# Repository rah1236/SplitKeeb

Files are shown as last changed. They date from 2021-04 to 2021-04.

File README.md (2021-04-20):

# SplitKeeb

### SplitKeeb is my custom designed split keyboard based on the QMK Firmware and 2 Arduino Pro Micros.

Split Keyboard
(No keycaps because I can't afford them at the moment :])

KiCad view

Real Life PCB

This is a *split* keyboard design, and uses I2C to communicate over a TRRS audio cable (4 poles). 

The parts list is as follows:
* 62 of any Cherry MX style key Switch
* 62 1N4148 Zener Diodes
* 2 identical Resistors from a range of 2.2k Ohms to 10k Ohms (4.7k recommended) 
* 2 Arduino Pro Micros
* 2 PJ-320A TRRS Female Jacks
* 1 TRRS Male to Male wire
* 10 M3 x 8mm Bolts
* 10 M3 nuts

The 2 resistors are for the I2C line, make sure to solder them to whichever board you want to use as the 'main' side.

Make sure to plug in the TRRS cable **BEFORE** you plug in the USB cable, otherwise you risk shorts as the TRRS cable supplies power to the other board.

To program the keyboard, the eaisest method is to use the [QMK Toolbox](https://github.com/qmk/qmk_toolbox), and flash both Pro Micros with the same 'SplitKeeb.hex' file. After both boards have been flashed, plug in the TRRS cable, and then plug in USB, and the keyboard should work as normal. 

Thanks to Rayyan and David for helping me figure out the firmware :)

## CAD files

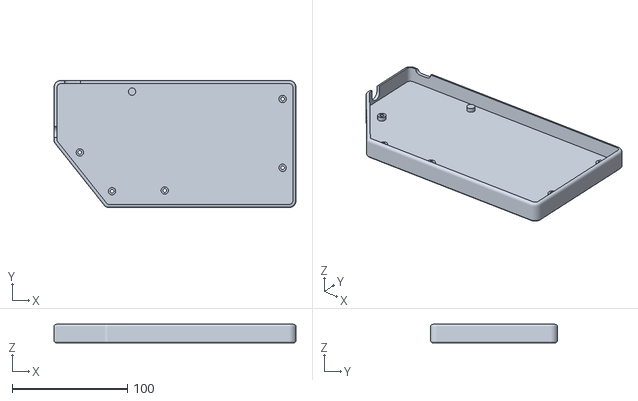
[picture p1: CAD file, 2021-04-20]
CaseFiles/RightSide.stl
209.9 x 110.2 x 16.1

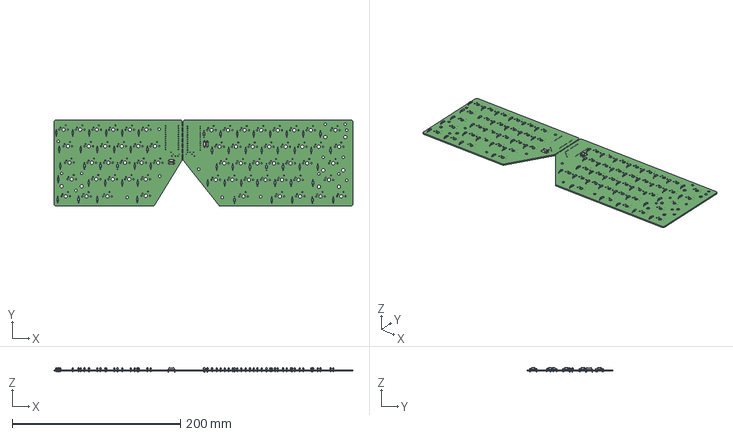
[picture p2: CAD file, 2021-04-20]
SplitKeebKiCad/kb.step
355.6 x 102.2 x 5.51 mm

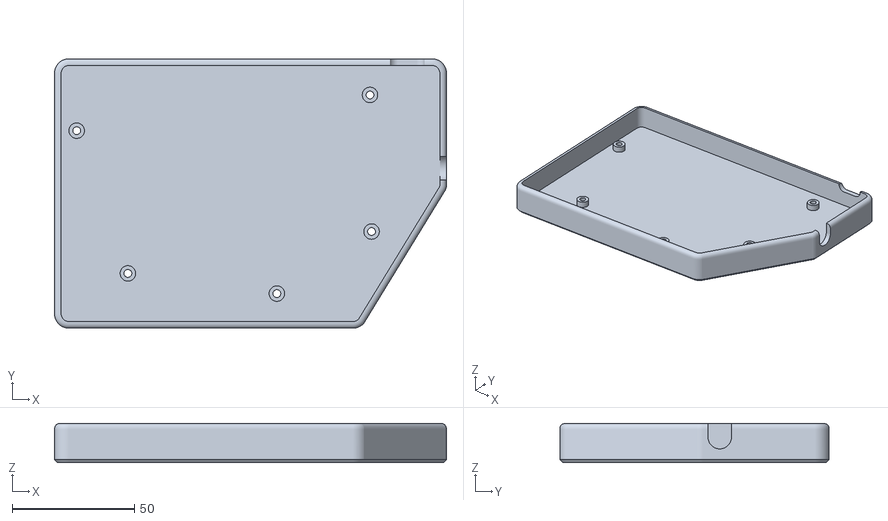
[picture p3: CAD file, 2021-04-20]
CaseFiles/LeftSide.stl
160.4 x 110.2 x 16.1

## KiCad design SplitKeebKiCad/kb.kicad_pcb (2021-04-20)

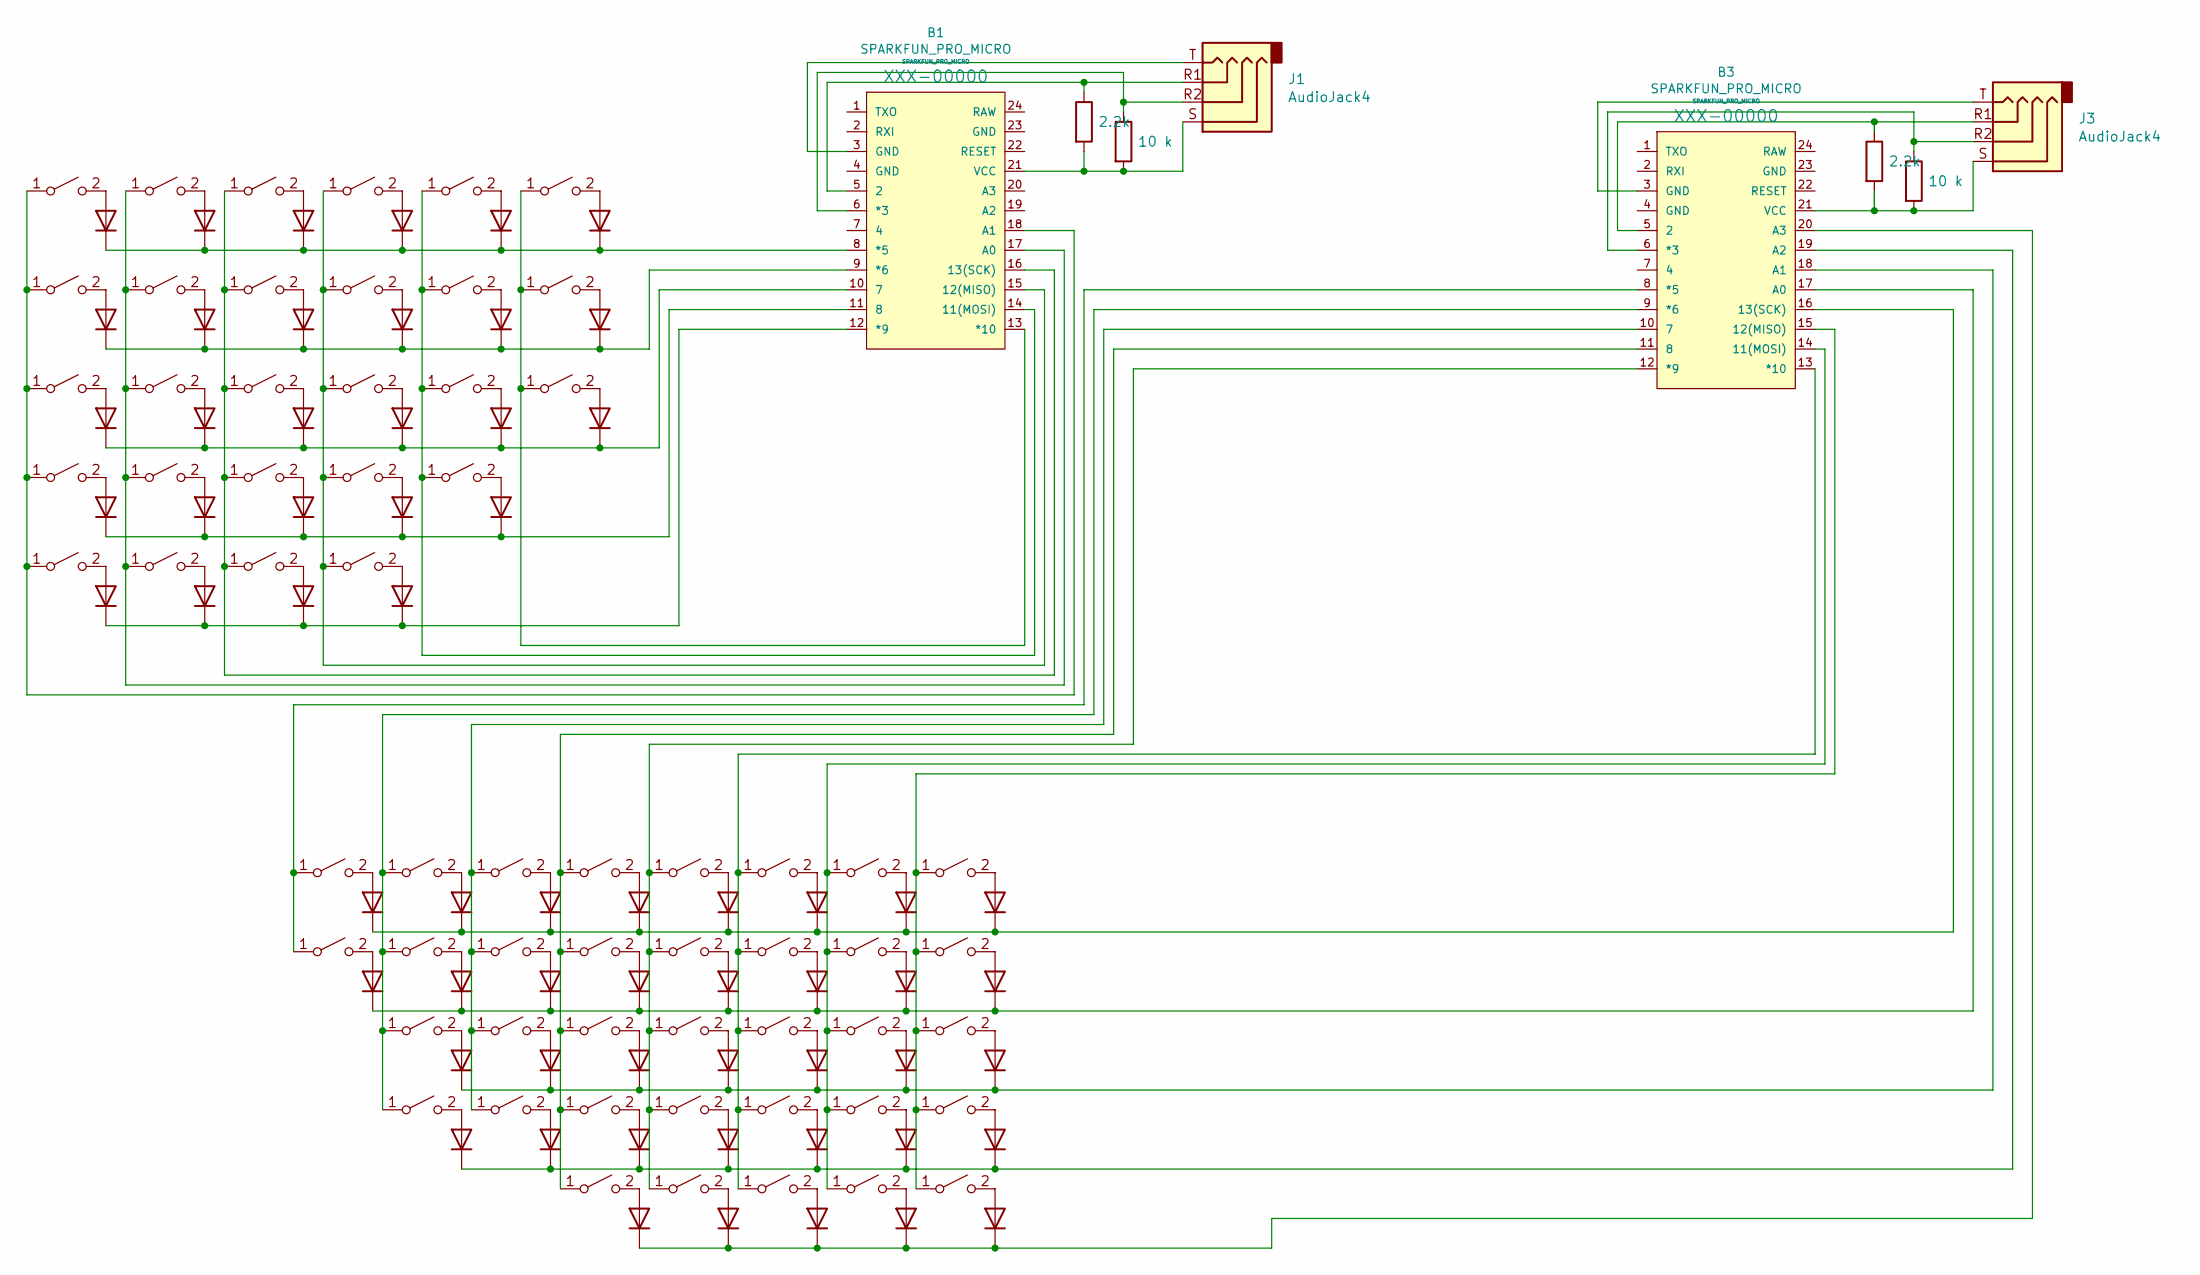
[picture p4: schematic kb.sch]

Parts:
A1: Q; SW_Cherry_MX_1.00u_PCB
Alt1: Q; SW_Cherry_MX_1.25u_PCB
B1, B3: SPARKFUN_PRO_MICRO
B2: b; SW_Cherry_MX_1.00u_PCB
Bar1: |; SW_Cherry_MX_1.50u_PCB
Bckspce1: Back; SW_Cherry_MX_2.00u_PCB
C1: Q; SW_Cherry_MX_1.00u_PCB
Caps1: Q; SW_Cherry_MX_1.75u_PCB
Colon1: ;; SW_Cherry_MX_1.00u_PCB
Ctrl1: Q; SW_Cherry_MX_1.25u_PCB
D1, D2, D3, D4, D5, D6, D7, D8, D9, D10, D11, D12, D13, D14, D15, D16, D17, D18, D19, D20, D21, D22, D23, D24, D25, D26, D27, D29, D30, D31, D32, D33, D34, D35, D36, D37, D38, D39, D40, D41, D42, D43, D44, D45, D46, D47, D48, D49, D50, D51, D52, D53, D54, D55, D56, D57, D58, D59, D60, D61, D62, D63: 1N4148; D_DO-35_SOD27_P7.62mm_Horizontal
D28: Q; SW_Cherry_MX_1.00u_PCB
E1: Q; SW_Cherry_MX_1.00u_PCB
Eight1: 8; SW_Cherry_MX_1.00u_PCB
Enter1: enter; SW_Cherry_MX_2.25u_PCB
EqualsSign1: =+; SW_Cherry_MX_1.00u_PCB
F1: Q; SW_Cherry_MX_1.00u_PCB
Five1: Q; SW_Cherry_MX_1.00u_PCB
Four1: Q; SW_Cherry_MX_1.00u_PCB
G1: Q; SW_Cherry_MX_1.00u_PCB
H1: h; SW_Cherry_MX_1.00u_PCB
I1: i; SW_Cherry_MX_1.00u_PCB
J1, J3: AudioJack4; TRRS-PJ-320A
J2: j; SW_Cherry_MX_1.00u_PCB
K1: k; SW_Cherry_MX_1.00u_PCB
L1: l; SW_Cherry_MX_1.00u_PCB
LeftAligator1: <; SW_Cherry_MX_1.00u_PCB
LeftBracket1: [; SW_Cherry_MX_1.00u_PCB
M1: m; SW_Cherry_MX_1.00u_PCB
MenuButton1: Menu; SW_Cherry_MX_1.25u_PCB
N1: n; SW_Cherry_MX_1.00u_PCB
Nine1: 9; SW_Cherry_MX_1.00u_PCB
O1: o; SW_Cherry_MX_1.00u_PCB
One1: 1; SW_Cherry_MX_1.00u_PCB
P1: p; SW_Cherry_MX_1.00u_PCB
Q1: Q; SW_Cherry_MX_1.00u_PCB
QuestionMark1: ?; SW_Cherry_MX_1.00u_PCB
QuoteSign1: \"; SW_Cherry_MX_1.00u_PCB
R1, R4: 2.2k; R_Axial_DIN0207_L6.3mm_D2.5mm_P7.62mm_Horizontal
R2, R5: 10 k; R_Axial_DIN0207_L6.3mm_D2.5mm_P7.62mm_Horizontal
R3: Q; SW_Cherry_MX_1.00u_PCB
RightAlligaotr1: >; SW_Cherry_MX_1.00u_PCB
RightAlt1: RAlt; SW_Cherry_MX_1.25u_PCB
RightBracket1: ]; SW_Cherry_MX_1.00u_PCB
RightCtrl1: RCTRL; SW_Cherry_MX_1.25u_PCB
RightShift1: RShift; SW_Cherry_MX_2.75u_PCB
RightSpace1: RSpace; SW_Cherry_MX_1.00u_PCB
RightWindows1: RWindows; SW_Cherry_MX_1.25u_PCB
S1: Q; SW_Cherry_MX_1.00u_PCB
Seven1: 7; SW_Cherry_MX_1.00u_PCB
Shift1: Q; SW_Cherry_MX_2.25u_PCB
Six1: 6; SW_Cherry_MX_1.00u_PCB
Space1: Q; SW_Cherry_MX_1.00u_PCB
T1: Q; SW_Cherry_MX_1.00u_PCB
Tab1: esc; SW_Cherry_MX_1.50u_PCB
Two1: Q; SW_Cherry_MX_1.00u_PCB
U1: u; SW_Cherry_MX_1.00u_PCB
UnderScore1: _; SW_Cherry_MX_1.00u_PCB
V1: Q; SW_Cherry_MX_1.00u_PCB
W1: Q; SW_Cherry_MX_1.00u_PCB
Windows1: Q; SW_Cherry_MX_1.25u_PCB
X1: Q; SW_Cherry_MX_1.00u_PCB
Y1: y; SW_Cherry_MX_1.00u_PCB
Z1: Q; SW_Cherry_MX_1.00u_PCB
Zero1: 0; SW_Cherry_MX_1.00u_PCB
esc1: esc; SW_Cherry_MX_1.00u_PCB
three1: Q; SW_Cherry_MX_1.00u_PCB

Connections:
unnamed: A1.1 (A), B1.17 (A0), One1.1 (A), Q1.1 (A), Windows1.1 (A), Z1.1 (A)
unnamed: A1.2 (B), D8.2 (A)
unnamed: Alt1.1 (A), B1.16 (13(SCK)), S1.1 (A), Two1.1 (A), W1.1 (A), X1.1 (A)
unnamed: Alt1.2 (B), D15.2 (A)
unnamed: B1.5 (2), J1.R1, R1.1
unnamed: B1.6 (*3), J1.R2, R2.1
unnamed: B1.8 (*5), D1.1 (K), D6.1 (K), D11.1 (K), D16.1 (K), D21.1 (K), D25.1 (K)
unnamed: B1.9 (*6), D2.1 (K), D7.1 (K), D12.1 (K), D17.1 (K), D22.1 (K), D26.1 (K)
unnamed: B1.10 (7), D3.1 (K), D8.1 (K), D13.1 (K), D18.1 (K), D23.1 (K), D27.1 (K)
unnamed: B1.11 (8), D4.1 (K), D9.1 (K), D14.1 (K), D19.1 (K), D24.1 (K)
unnamed: B1.12 (*9), D5.1 (K), D10.1 (K), D15.1 (K), D20.1 (K)
unnamed: B1.13 (*10), Five1.1 (A), G1.1 (A), T1.1 (A)
unnamed: B1.14 (11(MOSI)), F1.1 (A), Four1.1 (A), R3.1 (A), V1.1 (A)
unnamed: B1.15 (12(MISO)), C1.1 (A), D28.1 (A), E1.1 (A), Space1.1 (A), three1.1 (A)
unnamed: B1.18 (A1), Caps1.1 (A), Ctrl1.1 (A), Shift1.1 (A), Tab1.1 (A), esc1.1 (A)
unnamed: B1.21 (VCC), J1.S, R1.2, R2.2
unnamed: B2.1 (A), B3.9 (*6), H1.1 (A), Seven1.1 (A), U1.1 (A)
unnamed: B2.2 (B), D34.2 (A)
unnamed: B3.5 (2), J3.R1, R4.1
unnamed: B3.6 (*3), J3.R2, R5.1
unnamed: B3.8 (*5), Six1.1 (A), Y1.1 (A)
unnamed: B3.10 (7), Eight1.1 (A), I1.1 (A), J2.1 (A), N1.1 (A)
unnamed: B3.11 (8), K1.1 (A), M1.1 (A), Nine1.1 (A), O1.1 (A), RightSpace1.1 (A)
unnamed: B3.12 (*9), L1.1 (A), LeftAligator1.1 (A), P1.1 (A), RightAlt1.1 (A), Zero1.1 (A)
unnamed: B3.13 (*10), Colon1.1 (A), LeftBracket1.1 (A), RightAlligaotr1.1 (A), RightWindows1.1 (A), UnderScore1.1 (A)
unnamed: B3.14 (11(MOSI)), EqualsSign1.1 (A), MenuButton1.1 (A), QuestionMark1.1 (A), QuoteSign1.1 (A), RightBracket1.1 (A)
unnamed: B3.15 (12(MISO)), Bar1.1 (A), Bckspce1.1 (A), Enter1.1 (A), RightCtrl1.1 (A), RightShift1.1 (A)
unnamed: B3.16 (13(SCK)), D29.1 (K), D31.1 (K), D35.1 (K), D39.1 (K), D44.1 (K), D49.1 (K), D54.1 (K), D59.1 (K)
unnamed: B3.17 (A0), D30.1 (K), D32.1 (K), D36.1 (K), D40.1 (K), D45.1 (K), D50.1 (K), D55.1 (K), D60.1 (K)
unnamed: B3.18 (A1), D33.1 (K), D37.1 (K), D41.1 (K), D46.1 (K), D51.1 (K), D56.1 (K), D61.1 (K)
unnamed: B3.19 (A2), D34.1 (K), D38.1 (K), D42.1 (K), D47.1 (K), D52.1 (K), D57.1 (K), D62.1 (K)
unnamed: B3.20 (A3), D43.1 (K), D48.1 (K), D53.1 (K), D58.1 (K), D63.1 (K)
unnamed: B3.21 (VCC), J3.S, R4.2, R5.2
unnamed: Bar1.2 (B), D60.2 (A)
unnamed: Bckspce1.2 (B), D59.2 (A)
unnamed: C1.2 (B), D19.2 (A)
unnamed: Caps1.2 (B), D3.2 (A)
unnamed: Colon1.2 (B), D51.2 (A)
unnamed: Ctrl1.2 (B), D5.2 (A)
unnamed: D1.2 (A), esc1.2 (B)
unnamed: D2.2 (A), Tab1.2 (B)
unnamed: D4.2 (A), Shift1.2 (B)
unnamed: D6.2 (A), One1.2 (B)
unnamed: D7.2 (A), Q1.2 (B)
unnamed: D9.2 (A), Z1.2 (B)
unnamed: D10.2 (A), Windows1.2 (B)
unnamed: D11.2 (A), Two1.2 (B)
unnamed: D12.2 (A), W1.2 (B)
unnamed: D13.2 (A), S1.2 (B)
unnamed: D14.2 (A), X1.2 (B)
unnamed: D16.2 (A), three1.2 (B)
unnamed: D17.2 (A), E1.2 (B)
unnamed: D18.2 (A), D28.2 (B)
unnamed: D20.2 (A), Space1.2 (B)
unnamed: D21.2 (A), Four1.2 (B)
unnamed: D22.2 (A), R3.2 (B)
unnamed: D23.2 (A), F1.2 (B)
unnamed: D24.2 (A), V1.2 (B)
unnamed: D25.2 (A), Five1.2 (B)
unnamed: D26.2 (A), T1.2 (B)
unnamed: D27.2 (A), G1.2 (B)
unnamed: D29.2 (A), Six1.2 (B)
unnamed: D30.2 (A), Y1.2 (B)
unnamed: D31.2 (A), Seven1.2 (B)
unnamed: D32.2 (A), U1.2 (B)
unnamed: D33.2 (A), H1.2 (B)
unnamed: D35.2 (A), Eight1.2 (B)
unnamed: D36.2 (A), I1.2 (B)
unnamed: D37.2 (A), J2.2 (B)
unnamed: D38.2 (A), N1.2 (B)
unnamed: D39.2 (A), Nine1.2 (B)
unnamed: D40.2 (A), O1.2 (B)
unnamed: D41.2 (A), K1.2 (B)
unnamed: D42.2 (A), M1.2 (B)
unnamed: D43.2 (A), RightSpace1.2 (B)
unnamed: D44.2 (A), Zero1.2 (B)
unnamed: D45.2 (A), P1.2 (B)
unnamed: D46.2 (A), L1.2 (B)
unnamed: D47.2 (A), LeftAligator1.2 (B)
unnamed: D48.2 (A), RightAlt1.2 (B)
unnamed: D49.2 (A), UnderScore1.2 (B)
unnamed: D50.2 (A), LeftBracket1.2 (B)
unnamed: D52.2 (A), RightAlligaotr1.2 (B)
unnamed: D53.2 (A), RightWindows1.2 (B)
unnamed: D54.2 (A), EqualsSign1.2 (B)
unnamed: D55.2 (A), RightBracket1.2 (B)
unnamed: D56.2 (A), QuoteSign1.2 (B)
unnamed: D57.2 (A), QuestionMark1.2 (B)
unnamed: D58.2 (A), MenuButton1.2 (B)
unnamed: D61.2 (A), Enter1.2 (B)
unnamed: D62.2 (A), RightShift1.2 (B)
unnamed: D63.2 (A), RightCtrl1.2 (B)

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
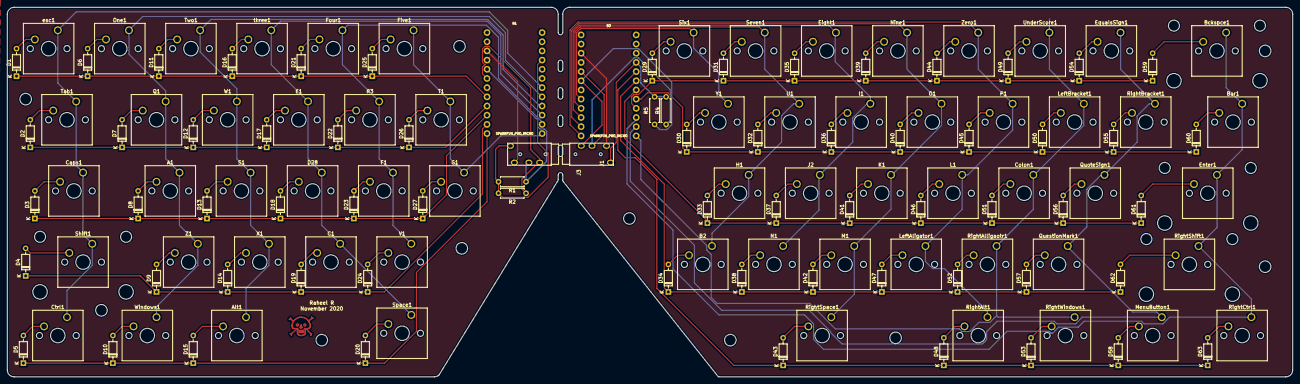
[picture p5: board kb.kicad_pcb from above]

Board: 2 copper layers, 355.6 x 102.2 mm, 143 parts (0 on the bottom side), 94 nets.

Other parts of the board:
 : MountingHole_3.2mm_M3
 #2,  #3,  #4,  #5,  #6,  #7,  #8,  #9,  #10: MountingHole_3.2mm_M3
 #11: Symbol_Danger_CopperTop_Small

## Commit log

2021-04-20 Uploaded GRBR FIles
    [kb-B_Cu.gbr, kb-B_Mask.gbr, kb-B_Paste.gbr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]
2021-04-20 Added KiCad files and Hex files
    [kb-B_Cu.gbr, kb-B_Mask.gbr, kb-B_Paste.gbr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]
2021-04-20 added 3d printable cases and uncompiled firmware
    [LeftSide.stl, RightSide.stl]
